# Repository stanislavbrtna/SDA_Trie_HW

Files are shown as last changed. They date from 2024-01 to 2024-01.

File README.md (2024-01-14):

# SDA Trié Hardware Sources
Trié is third iteration of the SDA design, it tries to merge the form factor of Sony Clié V-body and phone functionality of the Palm Treo devices, so Trié. In the pcb directory are KiCad project files for the Boards used in the SDA. In the case Directory there are FreeCAD files for the SDA case. You can find more info about the SDA Project on its [project page](https://hackaday.io/project/35165-sda-the-best-new-pda) on hackaday.io.

This design is work-in-progress.

## Known Bugs

## Case notes

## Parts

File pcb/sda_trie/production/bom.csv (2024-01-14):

Designator | Footprint | Quantity | Value | LCSC Part #
C1 | 0805 | 1 | 100n
C10 | 0805 | 1 | 100n
C11 | 0805 | 1 | 100n
C12 | 0805 | 1 | 100n
C13 | 0805 | 1 | 100n
C14 | 0805 | 1 | 100n
C15 | 0805 | 1 | 100n
C16 | 0805 | 1 | 100n
C17 | 0805 | 1 | 100n
C18 | 0805 | 1 | 100n
C19 | 0805 | 1 | 2.2u
C2 | 0805 | 1 | 100n
C21 | 0805 | 1 | 4.7u
C22 | 0805 | 1 | ??
C23 | 0805 | 1 | ??
C24 | 0805 | 1 | 10u
C25 | 0805 | 1 | 47p
C26 | 0805 | 1 | 47p
C27 | 0805 | 1 | 10u
C28 | 0805 | 1 | 100n
C29 | 0805 | 1 | 2.2u
C3 | 0805 | 1 | ??
C30 | 0805 | 1 | 10u
C31 | 0805 | 1 | 4.7u
C32 | 0805 | 1 | 100n
C33 | 0805 | 1 | 47u
C34 | 0805 | 1 | 100n
C35 | 0805 | 1 | 10u
C36 | 0805 | 1 | 2.2u
C37 | 0805 | 1 | 100n
C38 | 0805 | 1 | 10u
C39 | 0805 | 1 | 4.7u
C4 | 0805 | 1 | ??
C40 | 0805 | 1 | 22u
C41 | 0805 | 1 | 2.2u
C42 | 0805 | 1 | 10u
C43 | 0805 | 1 | 100n
C44 | 0805 | 1 | 100n
C45 | 0805 | 1 | 2.2n
C46 | 0805 | 1 | 100n
C47 | 0805 | 1 | 2.2n
C48 | 0805 | 1 | ??
C49 | 0805 | 1 | 47u
C5 | 0805 | 1 | 100n
C50 | 0805 | 1 | 4.7u
C6 | 0805 | 1 | 2.2u
C7 | 0805 | 1 | 100n
C8 | 0805 | 1 | 2.2u
C9 | 0805 | 1 | 100n
D1 | LED_D3.0mm_FlatTop | 1 | SYS_LED
D2, D4, D7 | D_SOD-123 | 3 | 1N5819HW-7-F
D3 | LED_D3.0mm_FlatTop | 1 | CHRG_LED
D5 | D_SOD-123 | 1 | 1N4148W
D6 | D_SOD-123 | 1 | MBR0520
J1 | PinHeader_1x06_P1.00mm_Vertical | 1 | PROG
J10 | PinHeader_1x02_P1.00mm_Vertical | 1 | SPKR
J11 | 3.5 Jack | 1 | AudioJack
J2 | USB_C_Receptacle_XKB_U262-16XN-4BVC11 | 1 | USB_C_Receptacle_USB2.0
J3 | PinHeader_2x08_P1.00mm_Vertical | 1 | KEYBOARD
J4, J7 | PinHeader_2x05_P1.00mm_Vertical_SMD | 2 | Conn_02x05_Top_Bottom
J5 | PinHeader_1x02_P1.00mm_Horizontal | 1 | BATT
J6 | PinHeader_2x11_P1.00mm_Horizontal | 1 | HINGE
J8 | PinHeader_1x02_P1.00mm_Vertical | 1 | PWR_BTN
J9 | SD-Connector | 1 | Micro_SD_Card_Det
L1 | HCM1A4020V2 | 1 | 4.7uH
L2 | SDN0530MT100 | 1 | 10uH
Q1 | SOT-23 | 1 | IRLML6302
R1 | 0805 | 1 | 10k
R10 | 0805 | 1 | 10k
R11 | 0805 | 1 | 15k
R12 | 0805 | 1 | 10k
R13 | 0805 | 1 | 19K
R14 | 0805 | 1 | 2k
R15 | 0805 | 1 | 47k
R16 | 0805 | 1 | 47k
R17 | 0805 | 1 | 47k
R18 | 0805 | 1 | 47k
R19 | 0805 | 1 | 47k
R2 | 0805 | 1 | 10k
R20 | 0805 | 1 | placeholder
R21 | 0805 | 1 | 47k
R22 | 0805 | 1 | 680K
R23 | 0805 | 1 | 150K
R24 | 0805 | 1 | 470
R25 | 0805 | 1 | 470
R26 | 0805 | 1 | 13k3
R27 | 0805 | 1 | 40k2
R28 | 0805 | 1 | 5.2k
R29 | 0805 | 1 | 5.2k
R3 | 0805 | 1 | 15K
R30 | 0805 | 1 | 0
R4 | 0805 | 1 | 10k
R5 | 0805 | 1 | 15K
R6 | 0805 | 1 | 220
R7 | 0805 | 1 | 27
R8 | 0805 | 1 | 27R
R9 | 0805 | 1 | 470
SW1 | SW_SPST_B3S-1000 | 1 | RESET
TP1 | TestPoint_Pad_D1.0mm | 1 | VREFF
TP2 | TestPoint_Pad_D1.0mm | 1 | TP_VUSB
TP3 | TestPoint_Pad_D1.0mm | 1 | VBATT
TP4 | TestPoint_Pad_D1.0mm | 1 | 3.3V
TP5 | TestPoint_Pad_D1.0mm | 1 | 5V
U10 | LQFP-144_20x20mm_P0.5mm | 1 | STM32H743ZITx
U2 | TSOT-23 | 1 | TLV431
U3 | TSOT-23-6_HandSoldering | 1 | USBLC6
U4 | SOT-23-5_HandSoldering | 1 | AP22802AW5-7
U5 | SSOP-16_3.9x4.9mm_P0.635mm | 1 | FT230XS
U6 | SOT-23-5_HandSoldering | 1 | MCP73831-2-OT
U7 | TSSOP-20_4.4x6.5mm_P0.65mm | 1 | PCM5102
U8 | TSOT-23-5_HandSoldering | 1 | NCP1529
U9 | SOT-23-5_HandSoldering | 1 | LMR62014XMF
Y1 | SMDXT224 | 1 | 16Mhz
Y2 | 32.768K-85SMXR | 1 | 32.768

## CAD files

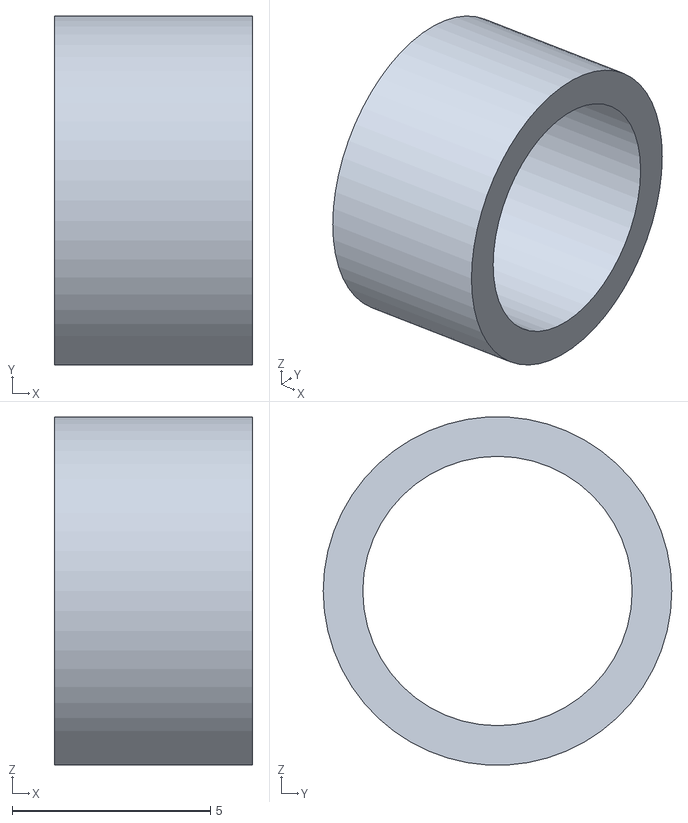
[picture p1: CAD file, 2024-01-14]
case/export/trié-fitting.stl
5.00 x 8.80 x 8.79

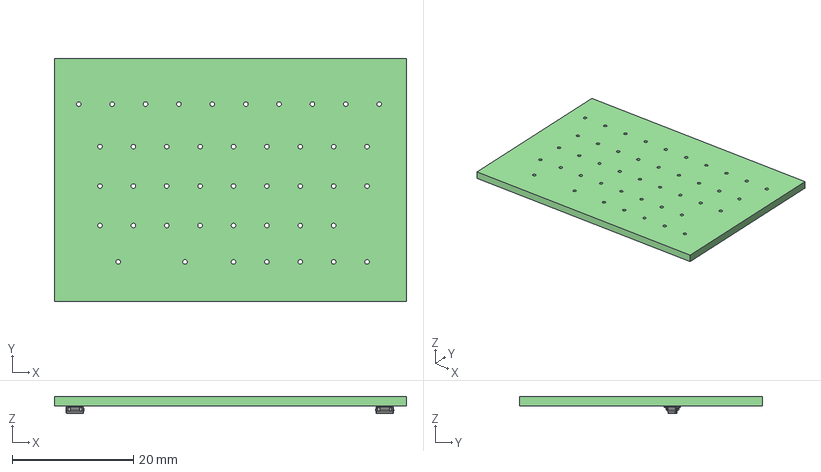
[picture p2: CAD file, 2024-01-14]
pcb/sda_trie/sda_trie_kbd.step
58.0 x 40.0 x 2.85 mm
sda_trie_kbd PCB

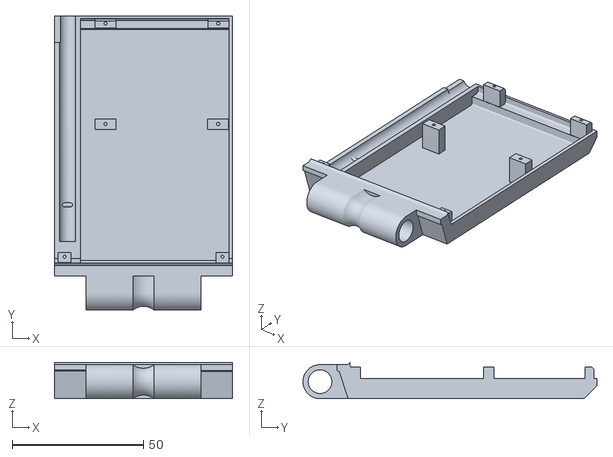
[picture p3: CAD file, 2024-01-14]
case/export/trié-bottom-base.stl
68.0 x 112.0 x 13.9

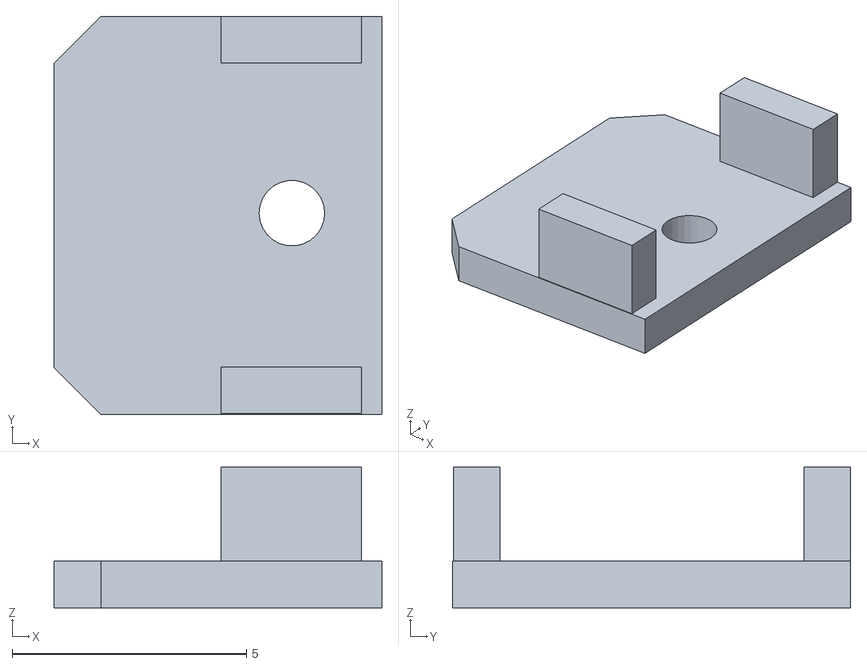
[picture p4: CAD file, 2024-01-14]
case/export/trié-lcd-holder-trie.stl
7.00 x 8.50 x 3.00

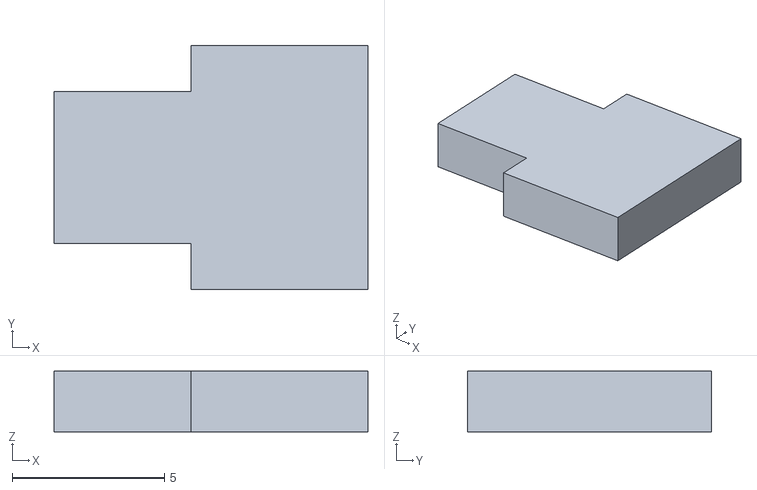
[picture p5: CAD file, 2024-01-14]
case/export/trié-pwr-btn-fillet.stl
10.3 x 8.00 x 2.00

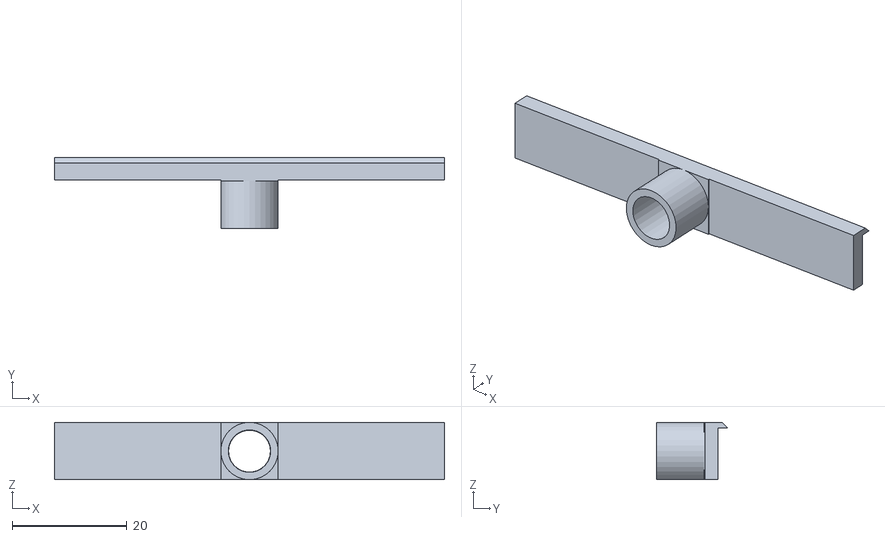
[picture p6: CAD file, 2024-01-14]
case/export/trié-top-hinge.stl
68.0 x 12.5 x 10.0

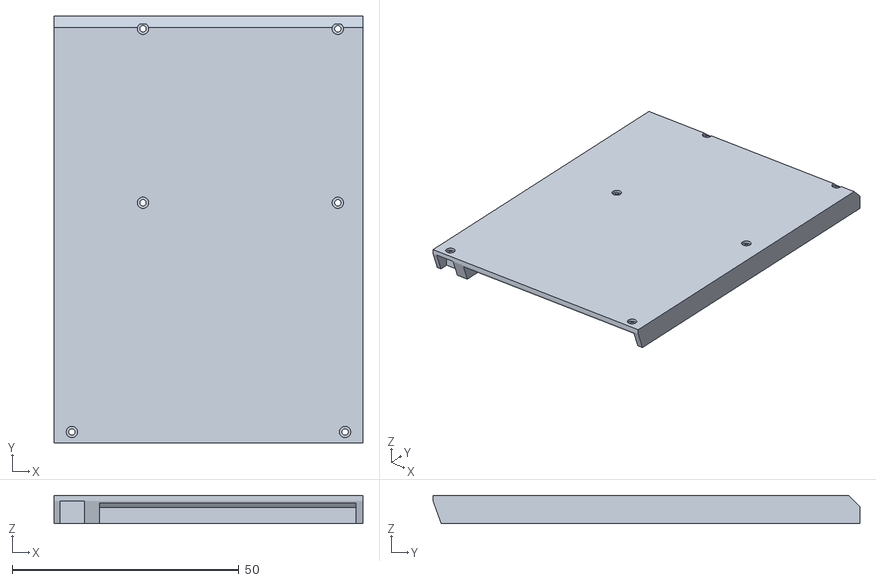
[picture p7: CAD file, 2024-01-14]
case/export/trié-bottom-cover.stl
68.0 x 94.1 x 6.20

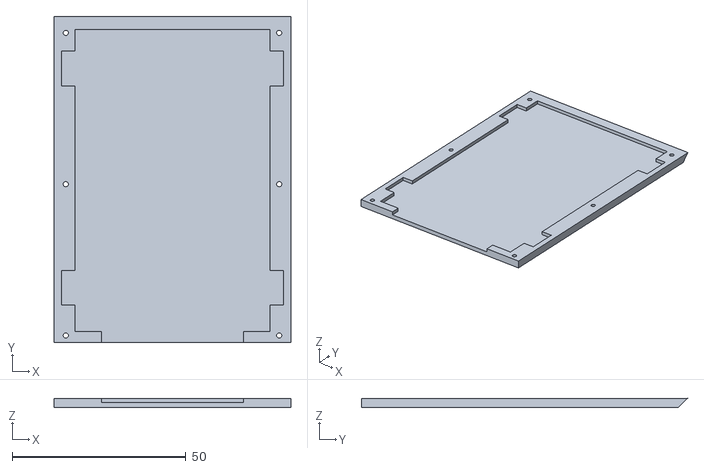
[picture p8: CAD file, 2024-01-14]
case/export/trié-top-cover.stl
68.0 x 93.7 x 2.70

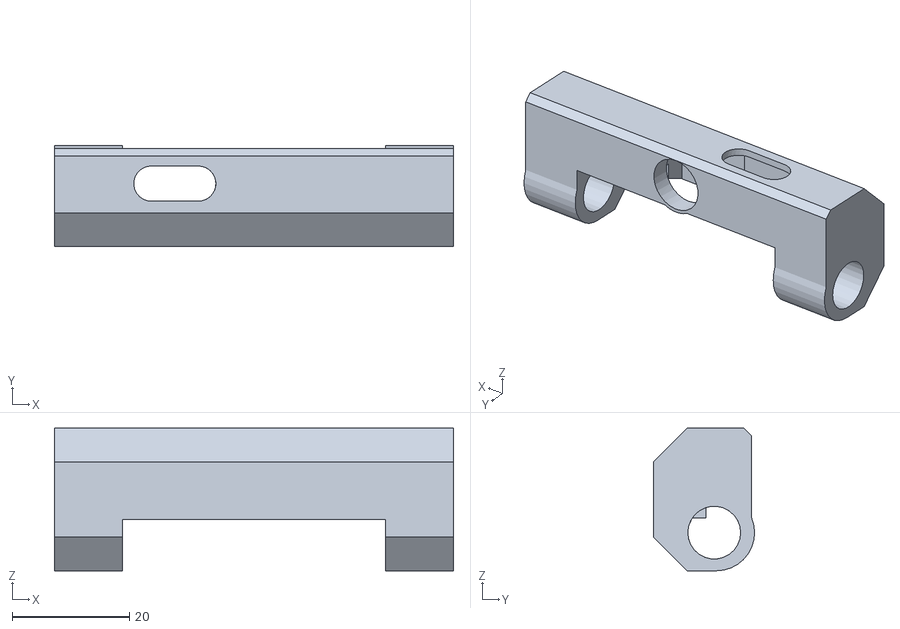
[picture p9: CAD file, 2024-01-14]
case/export/trié-pant.stl
68.0 x 17.2 x 24.3

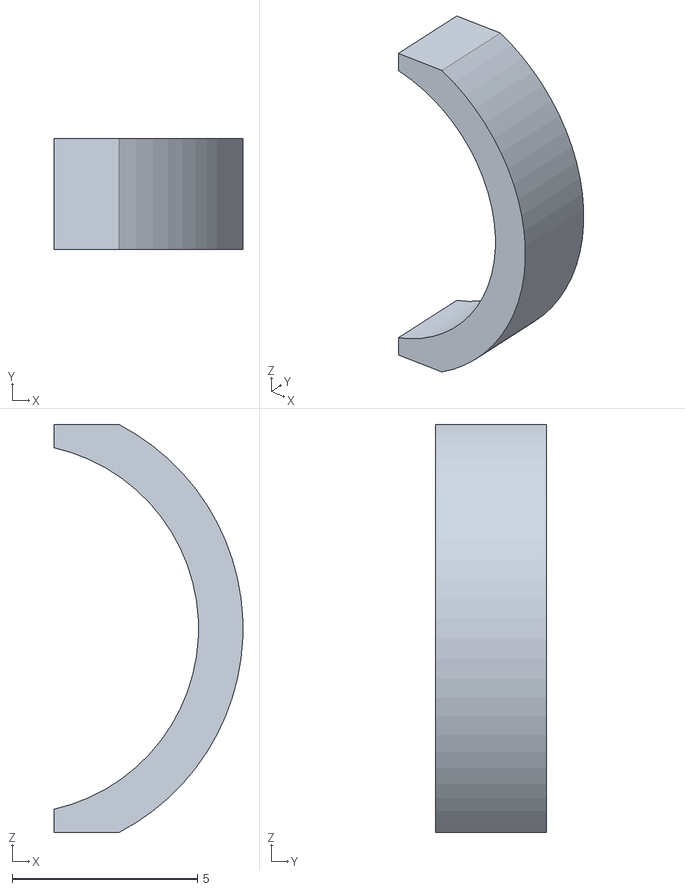
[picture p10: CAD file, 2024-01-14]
case/export/trié-lcd-rot-stop.stl
5.09 x 3.00 x 11.0

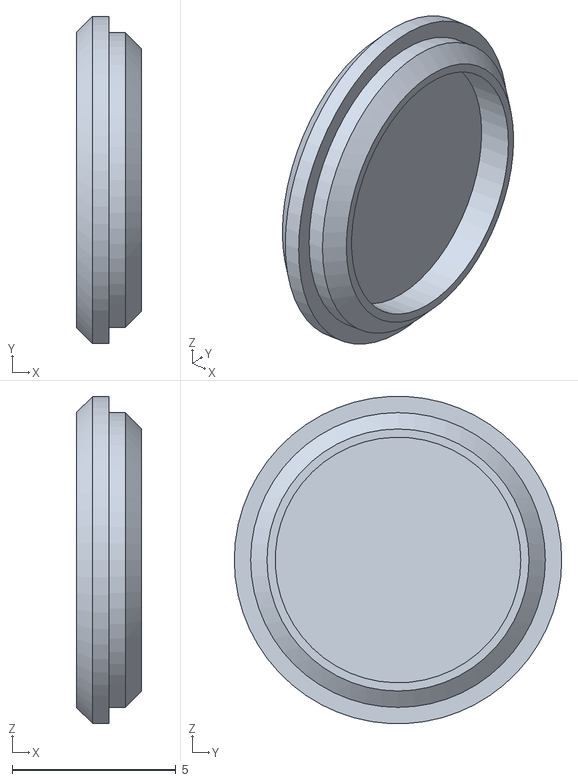
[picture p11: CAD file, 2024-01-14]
case/export/trié-sidecap.stl
2.00 x 10.0 x 9.99

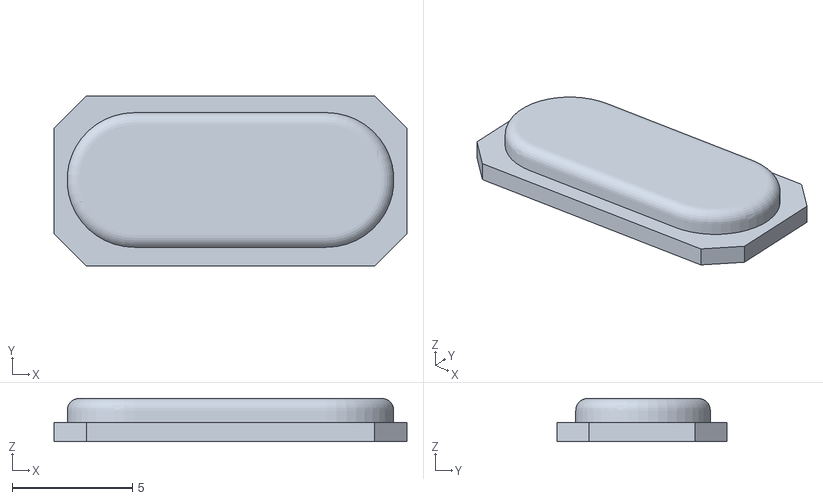
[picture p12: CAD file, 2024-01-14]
case/export/trié-pwrbtn.stl
14.7 x 7.09 x 1.80

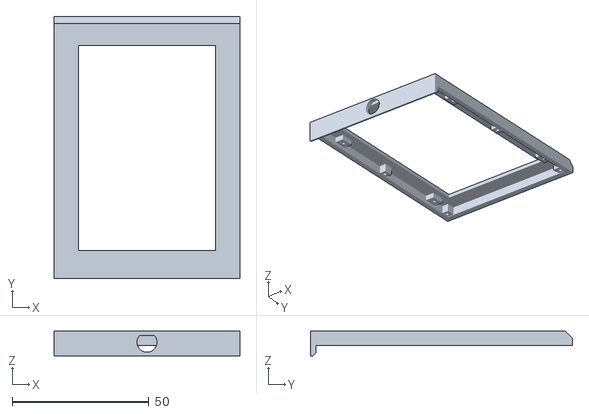
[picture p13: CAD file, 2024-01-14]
case/export/trié-top-base.stl
68.0 x 95.8 x 9.02

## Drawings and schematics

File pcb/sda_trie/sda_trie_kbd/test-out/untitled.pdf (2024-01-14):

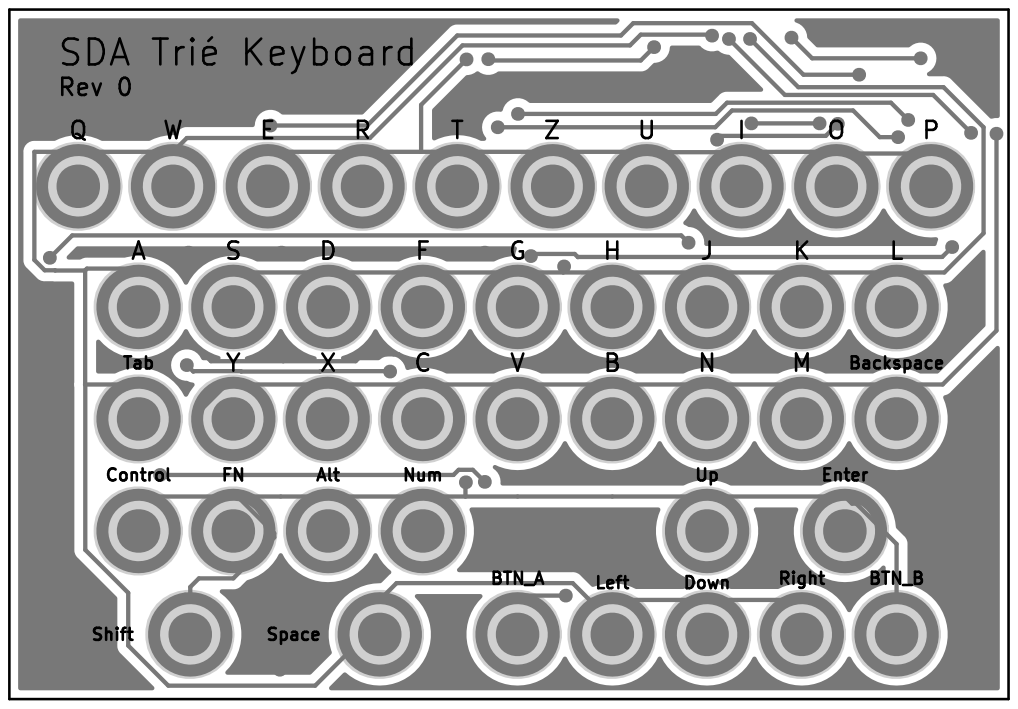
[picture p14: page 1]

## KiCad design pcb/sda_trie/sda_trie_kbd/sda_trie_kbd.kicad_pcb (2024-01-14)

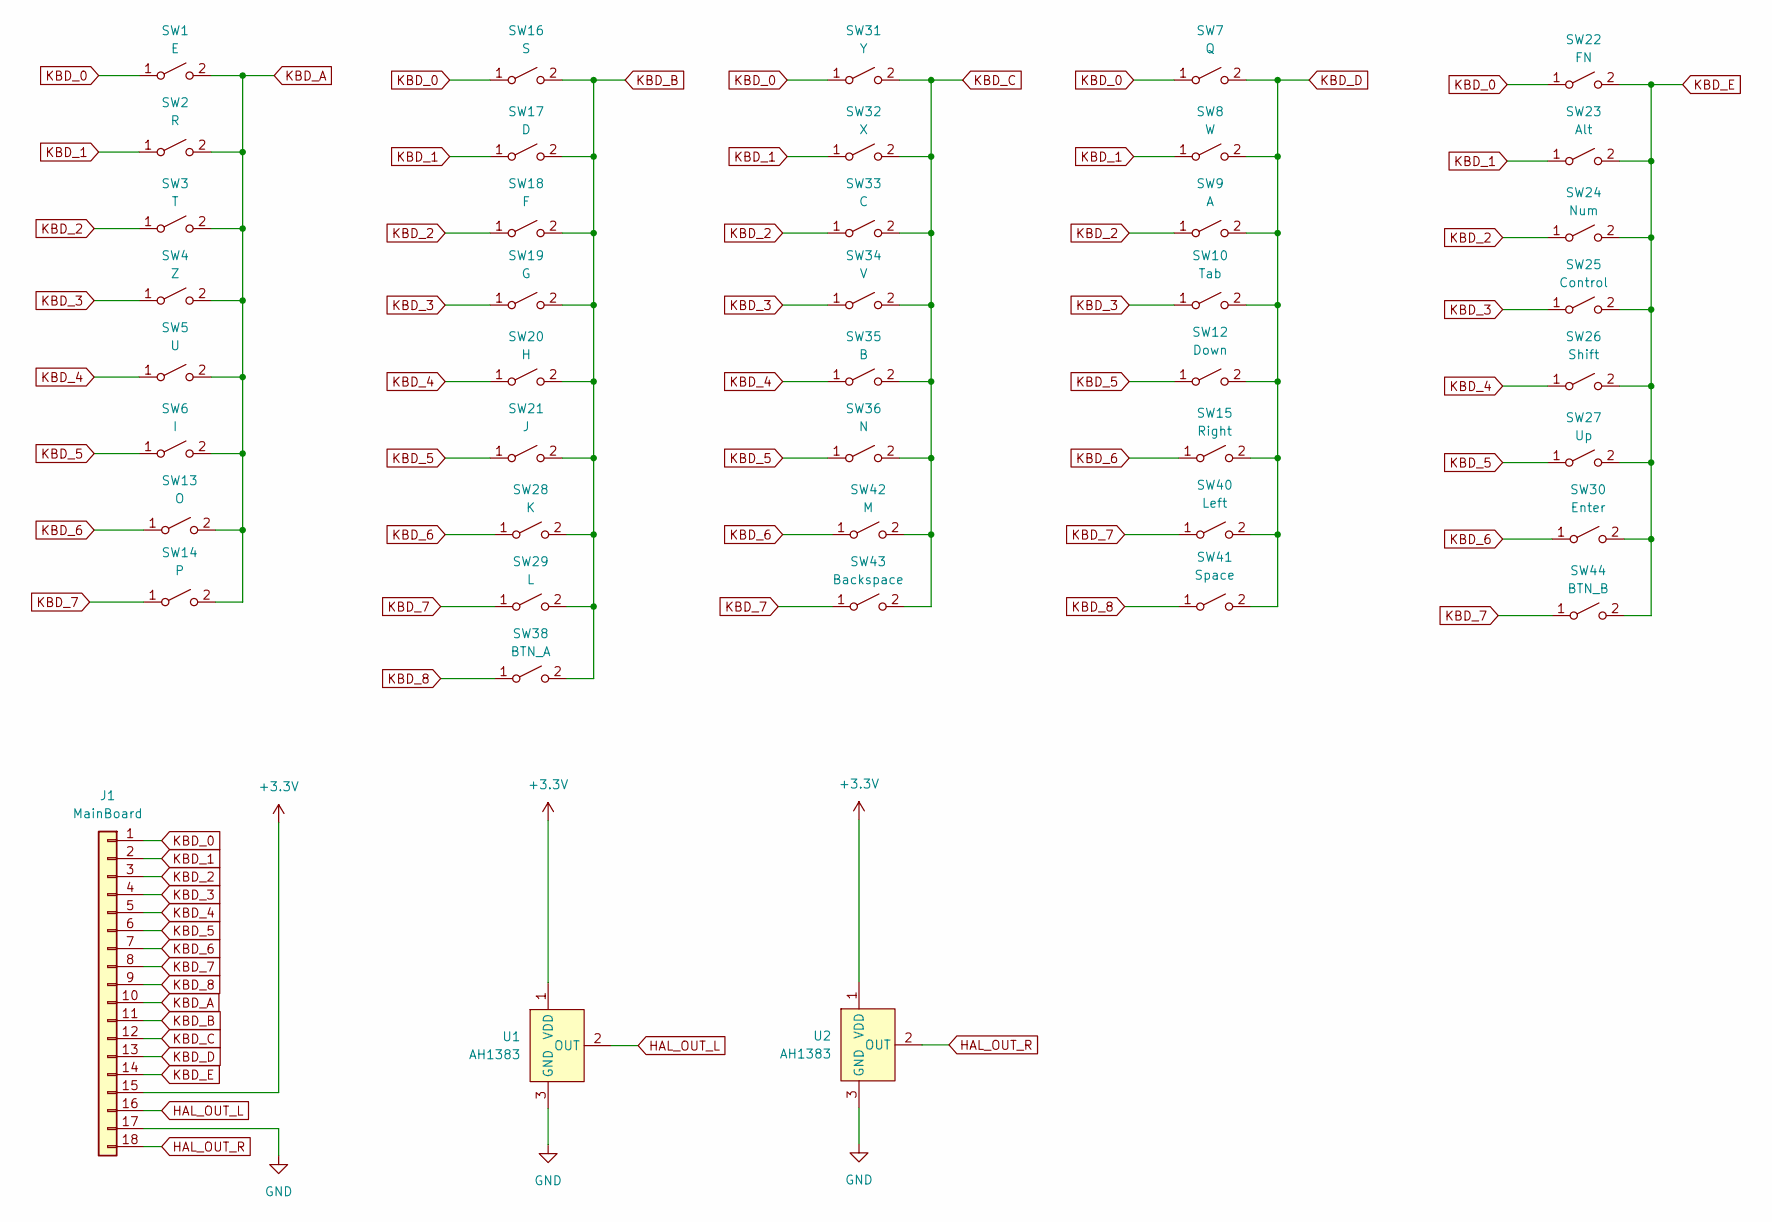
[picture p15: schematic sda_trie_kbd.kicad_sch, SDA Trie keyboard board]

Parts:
J1: MainBoard; TE_1-1734839-8_1x18-1MP_P0.5mm_Horizontal
SW1: E; TACT_4MM
SW2: R; TACT_4MM
SW3: T; TACT_4MM
SW4: Z; TACT_4MM
SW5: U; TACT_4MM
SW6: I; TACT_4MM
SW7: Q; TACT_4MM
SW8: W; TACT_4MM
SW9: A; TACT_4MM
SW10: Tab; TACT_4MM
SW12: Down; TACT_4MM
SW13: O; TACT_4MM
SW14: P; TACT_4MM
SW15: Right; TACT_4MM
SW16: S; TACT_4MM
SW17: D; TACT_4MM
SW18: F; TACT_4MM
SW19: G; TACT_4MM
SW20: H; TACT_4MM
SW21: J; TACT_4MM
SW22: FN; TACT_4MM
SW23: Alt; TACT_4MM
SW24: Num; TACT_4MM
SW25: Control; TACT_4MM
SW26: Shift; TACT_4MM
SW27: Up; TACT_4MM
SW28: K; TACT_4MM
SW29: L; TACT_4MM
SW30: Enter; TACT_4MM
SW31: Y; TACT_4MM
SW32: X; TACT_4MM
SW33: C; TACT_4MM
SW34: V; TACT_4MM
SW35: B; TACT_4MM
SW36: N; TACT_4MM
SW38: BTN_A; TACT_4MM
SW40: Left; TACT_4MM
SW41: Space; TACT_4MM
SW42: M; TACT_4MM
SW43: Backspace; TACT_4MM
SW44: BTN_B; TACT_4MM
U1, U2: AH1383; SOT-23

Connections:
+3.3V: J1.15, U1.1 (VDD), U2.1 (VDD)
GND: J1.17, U1.3 (GND), U2.3 (GND)
HAL_OUT_L: J1.16, U1.2 (OUT)
HAL_OUT_R: J1.18, U2.2 (OUT)
KBD_0: J1.1, SW1.1 (A), SW7.1 (A), SW16.1 (A), SW22.1 (A), SW31.1 (A)
KBD_1: J1.2, SW2.1 (A), SW8.1 (A), SW17.1 (A), SW23.1 (A), SW32.1 (A)
KBD_2: J1.3, SW3.1 (A), SW9.1 (A), SW18.1 (A), SW24.1 (A), SW33.1 (A)
KBD_3: J1.4, SW4.1 (A), SW10.1 (A), SW19.1 (A), SW25.1 (A), SW34.1 (A)
KBD_4: J1.5, SW5.1 (A), SW20.1 (A), SW26.1 (A), SW35.1 (A)
KBD_5: J1.6, SW6.1 (A), SW12.1 (A), SW21.1 (A), SW27.1 (A), SW36.1 (A)
KBD_6: J1.7, SW13.1 (A), SW15.1 (A), SW28.1 (A), SW30.1 (A), SW42.1 (A)
KBD_7: J1.8, SW14.1 (A), SW29.1 (A), SW40.1 (A), SW43.1 (A), SW44.1 (A)
KBD_8: J1.9, SW38.1 (A), SW41.1 (A)
KBD_A: J1.10, SW1.2 (B), SW2.2 (B), SW3.2 (B), SW4.2 (B), SW5.2 (B), SW6.2 (B), SW13.2 (B), SW14.2 (B)
KBD_B: J1.11, SW16.2 (B), SW17.2 (B), SW18.2 (B), SW19.2 (B), SW20.2 (B), SW21.2 (B), SW28.2 (B), SW29.2 (B), SW38.2 (B)
KBD_C: J1.12, SW31.2 (B), SW32.2 (B), SW33.2 (B), SW34.2 (B), SW35.2 (B), SW36.2 (B), SW42.2 (B), SW43.2 (B)
KBD_D: J1.13, SW7.2 (B), SW8.2 (B), SW9.2 (B), SW10.2 (B), SW12.2 (B), SW15.2 (B), SW40.2 (B), SW41.2 (B)
KBD_E: J1.14, SW22.2 (B), SW23.2 (B), SW24.2 (B), SW25.2 (B), SW26.2 (B), SW27.2 (B), SW30.2 (B), SW44.2 (B)

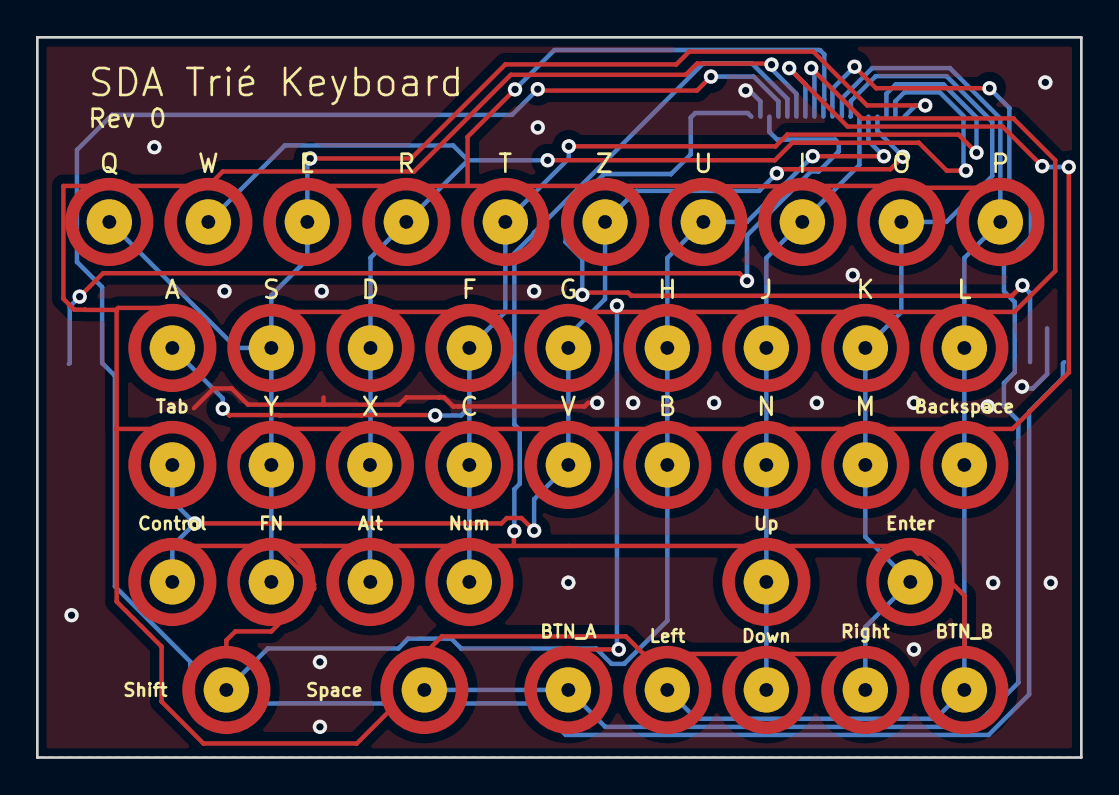
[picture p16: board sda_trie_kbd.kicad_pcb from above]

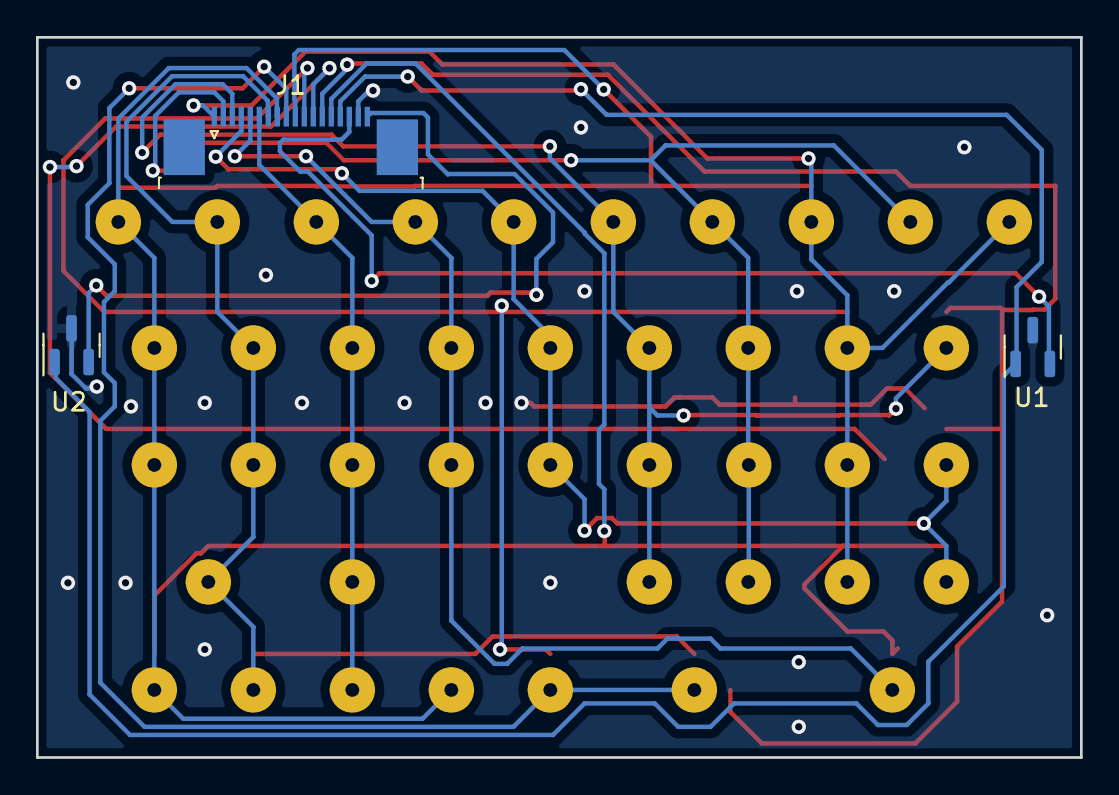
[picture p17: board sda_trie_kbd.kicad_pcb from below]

Board: 2 copper layers, 58.0 x 40.0 mm, 44 parts (3 on the bottom side), 18 nets.

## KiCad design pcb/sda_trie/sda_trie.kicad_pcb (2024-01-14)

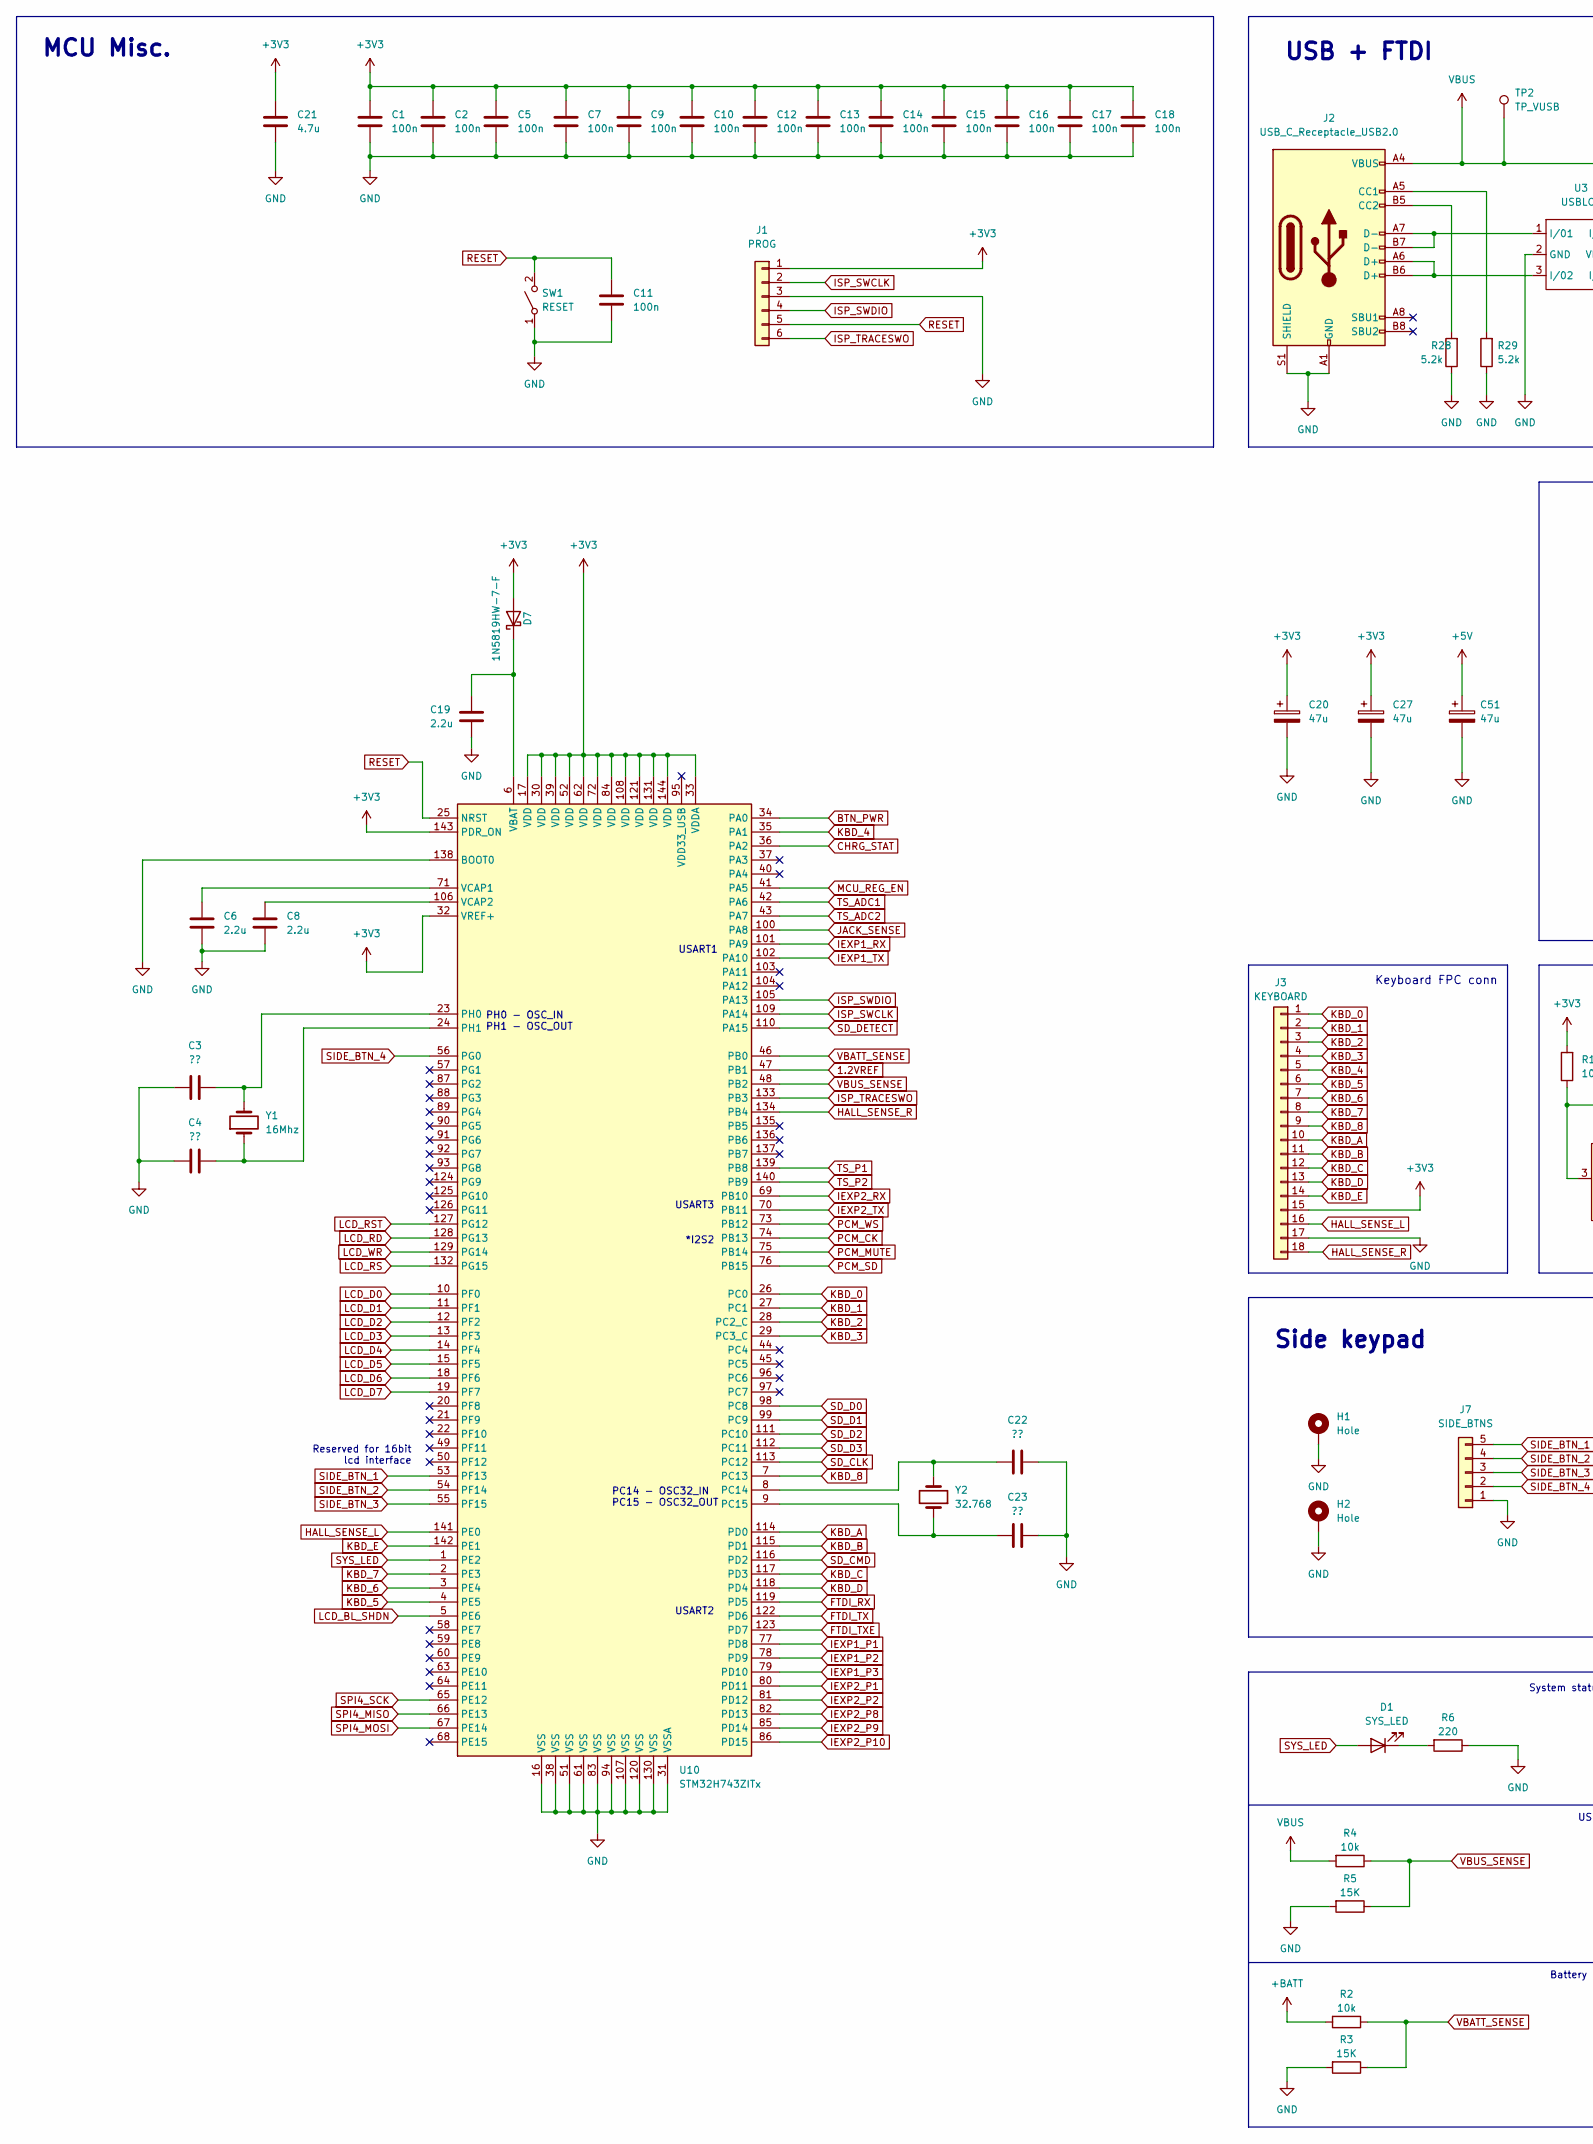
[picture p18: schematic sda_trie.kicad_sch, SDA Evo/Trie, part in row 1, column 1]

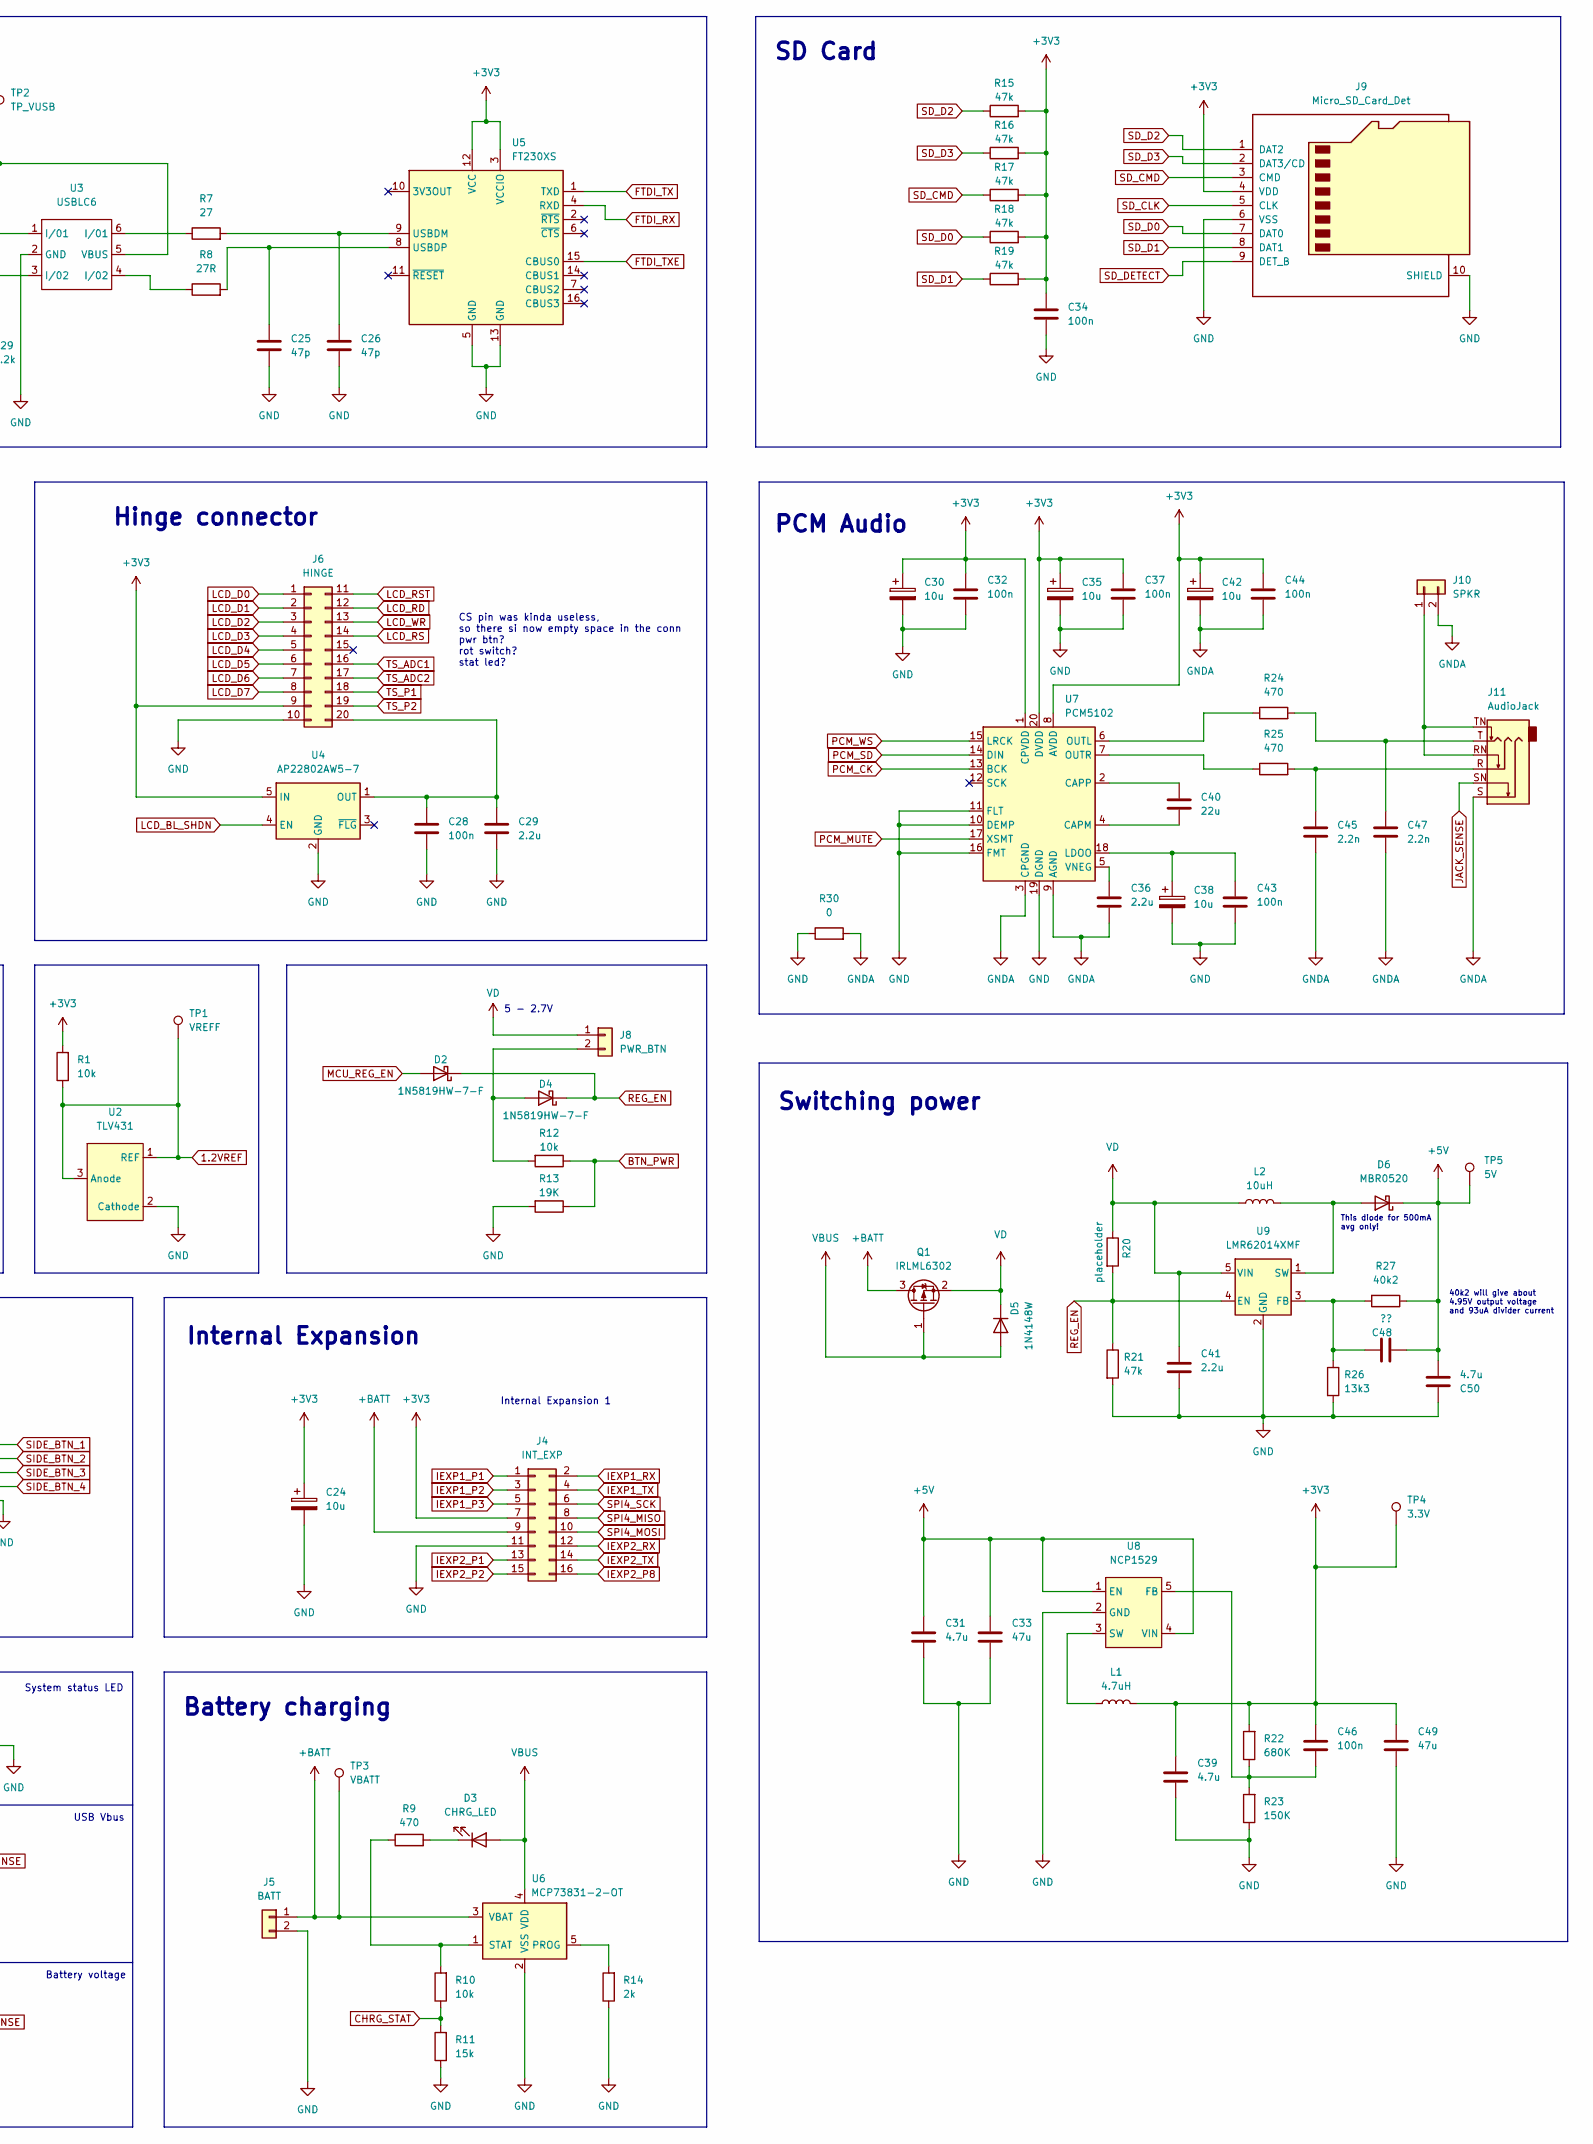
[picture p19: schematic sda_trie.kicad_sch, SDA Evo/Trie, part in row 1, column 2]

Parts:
C1, C2, C5, C7, C9, C10, C11, C12, C13, C14, C15, C16, C17, C18, C28, C32, C34, C37, C43, C44, C46: 100n; C_0805_2012Metric_Pad1.18x1.45mm_HandSolder
C3, C4, C22, C23, C48: ??; C_0805_2012Metric_Pad1.18x1.45mm_HandSolder
C6, C8, C19, C29, C36, C41: 2.2u; C_0805_2012Metric_Pad1.18x1.45mm_HandSolder
C20, C27, C51: 47u; CP_EIA-7343-15_Kemet-W_Pad2.25x2.55mm_HandSolder
C21, C31, C39, C50: 4.7u; C_0805_2012Metric_Pad1.18x1.45mm_HandSolder
C24, C30, C35, C38, C42: 10u; C_0805_2012Metric_Pad1.18x1.45mm_HandSolder
C25, C26: 47p; C_0805_2012Metric_Pad1.18x1.45mm_HandSolder
C33, C49: 47u; C_0805_2012Metric_Pad1.18x1.45mm_HandSolder
C40: 22u; C_0805_2012Metric_Pad1.18x1.45mm_HandSolder
C45, C47: 2.2n; C_0805_2012Metric_Pad1.18x1.45mm_HandSolder
D1: SYS_LED; LED_D3.0mm_FlatTop
D2, D4, D7: 1N5819HW-7-F; D_SOD-123
D3: CHRG_LED; LED_D3.0mm_FlatTop
D5: 1N4148W; D_SOD-123
D6: MBR0520; D_SOD-123
H1, H2: Hole; Mounting_Wuerth_WA-SMSI-M1.6_H1.5mm_9774015633
J1: PROG; PinHeader_1x06_P1.00mm_Vertical
J2: USB_C_Receptacle_USB2.0; USB_C_Receptacle_XKB_U262-16XN-4BVC11
J3: KEYBOARD; TE_1-1734839-8_1x18-1MP_P0.5mm_Horizontal
J4: INT_EXP; PinHeader_2x08_P1.00mm_Vertical_SMD
J5: BATT; PinHeader_1x02_P2.54mm_Horizontal
J6: HINGE; PinHeader_2x10_P1.00mm_Horizontal
J7: SIDE_BTNS; PinHeader_1x05_P1.00mm_Horizontal
J8: PWR_BTN; PinHeader_1x02_P1.00mm_Vertical
J9: Micro_SD_Card_Det; SD-Connector
J10: SPKR; PinHeader_1x02_P1.00mm_Vertical
J11: AudioJack; 3.5 Jack
L1: 4.7uH; HCM1A4020V2
L2: 10uH; SDN0530MT100
Q1: IRLML6302; SOT-23
R1, R2, R4, R10, R12: 10k; R_0805_2012Metric_Pad1.20x1.40mm_HandSolder
R3, R5: 15K; R_0805_2012Metric_Pad1.20x1.40mm_HandSolder
R6: 220; R_0805_2012Metric_Pad1.20x1.40mm_HandSolder
R7: 27; R_0805_2012Metric_Pad1.20x1.40mm_HandSolder
R8: 27R; R_0805_2012Metric_Pad1.20x1.40mm_HandSolder
R9, R24, R25: 470; R_0805_2012Metric_Pad1.20x1.40mm_HandSolder
R11: 15k; R_0805_2012Metric_Pad1.20x1.40mm_HandSolder
R13: 19K; R_0805_2012Metric_Pad1.20x1.40mm_HandSolder
R14: 2k; R_0805_2012Metric_Pad1.20x1.40mm_HandSolder
R15, R16, R17, R18, R19, R21: 47k; R_0805_2012Metric_Pad1.20x1.40mm_HandSolder
R20: placeholder; R_0805_2012Metric_Pad1.20x1.40mm_HandSolder
R22: 680K; R_0805_2012Metric_Pad1.20x1.40mm_HandSolder
R23: 150K; R_0805_2012Metric_Pad1.20x1.40mm_HandSolder
R26: 13k3; R_0805_2012Metric_Pad1.20x1.40mm_HandSolder
R27: 40k2; R_0805_2012Metric_Pad1.20x1.40mm_HandSolder
R28, R29: 5.2k; R_0805_2012Metric_Pad1.20x1.40mm_HandSolder
R30: 0; R_0805_2012Metric_Pad1.20x1.40mm_HandSolder
SW1: RESET; SW_SPST_B3S-1000
TP1: VREFF; TestPoint_Pad_D1.0mm
TP2: TP_VUSB; TestPoint_Pad_D1.0mm
TP3: VBATT; TestPoint_Pad_D1.0mm
TP4: 3.3V; TestPoint_Pad_D1.0mm
TP5: 5V; TestPoint_Pad_D1.0mm
U2: TLV431; TSOT-23
U3: USBLC6; TSOT-23-6_HandSoldering
U4: AP22802AW5-7; SOT-23-5_HandSoldering
U5: FT230XS; SSOP-16_3.9x4.9mm_P0.635mm
U6: MCP73831-2-OT; SOT-23-5_HandSoldering
U7: PCM5102; TSSOP-20_4.4x6.5mm_P0.65mm
U8: NCP1529; TSOT-23-5_HandSoldering
U9: LMR62014XMF; SOT-23-5_HandSoldering
U10: STM32H743ZITx; LQFP-144_20x20mm_P0.5mm
Y1: 16Mhz; SMDXT224
Y2: 32.768; 32.768K-85SMXR

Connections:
1.2VREF: R1.1, TP1.1, U2.1 (REF), U2.3 (Anode), U10.47 (PB1)
+3V3: C1.1, C2.1, C5.1, C7.1, C9.1, C10.1, C12.1, C13.1, C14.1, C15.1, C16.1, C17.1, C18.1, C20.1, C21.1, C24.1, C27.1, C30.1, C32.1, C34.1, C35.1, C37.1, C39.1, C42.1, C44.1, C46.1, C49.1, D7.2 (A), J1.1, J3.15, J4.7, J6.9, J9.4 (VDD), L1.2, R1.2, R15.2, R16.2, R17.2, R18.2, R19.2, R22.2, TP4.1, U4.5 (IN), U5.3 (VCCIO), U5.12 (VCC), U7.1 (CPVDD), U7.8 (AVDD), U7.20 (DVDD), U10.17 (VDD), U10.30 (VDD), U10.32 (VREF+), U10.33 (VDDA), U10.39 (VDD), U10.52 (VDD), U10.62 (VDD), U10.72 (VDD), U10.84 (VDD), U10.108 (VDD), U10.121 (VDD), U10.131 (VDD), U10.143 (PDR_ON), U10.144 (VDD)
+5V: C31.1, C33.1, C48.2, C50.1, C51.1, D6.1 (K), R27.1, TP5.1, U8.1 (EN), U8.4 (VIN)
+BATT: J4.9, J5.1, Q1.3 (D), R2.2, TP3.1, U6.3 (VBAT)
BTN_PWR: R12.1, R13.1, U10.34 (PA0)
CHRG_STAT: R10.1, R11.2, U10.36 (PA2)
FTDI_RX: U5.4 (RXD), U10.119 (PD5)
FTDI_TX: U5.1 (TXD), U10.122 (PD6)
FTDI_TXE: U5.15 (CBUS0), U10.123 (PD7)
GND: C1.2, C2.2, C3.1, C4.1, C5.2, C6.2, C7.2, C8.2, C9.2, C10.2, C11.2, C12.2, C13.2, C14.2, C15.2, C16.2, C17.2, C18.2, C19.2, C20.2, C21.2, C22.1, C23.1, C24.2, C25.2, C26.2, C27.2, C28.2, C29.2, C30.2, C31.2, C32.2, C33.2, C34.2, C35.2, C37.2, C38.2, C39.2, C41.2, C43.2, C49.2, C50.2, C51.2, H1.1, H2.1, J1.3, J2.A1 (GND), J2.A12 (GND), J2.B1 (GND), J2.B12 (GND), J2.S1 (SHIELD), J3.17, J4.11, J5.2, J6.10, J7.1, J9.6 (VSS), J9.10 (SHIELD), R3.2, R5.2, R6.1, R11.1, R13.2, R14.1, R21.2, R23.1, R26.2, R28.1, R29.1, R30.1, SW1.1 (A), U2.2 (Cathode), U3.2 (GND), U4.2 (GND), U5.5 (GND), U5.13 (GND), U6.2 (VSS), U7.10 (DEMP), U7.11 (FLT), U7.16 (FMT), U7.19 (DGND), U8.2 (GND), U9.2 (GND), U10.16 (VSS), U10.31 (VSSA), U10.38 (VSS), U10.51 (VSS), U10.61 (VSS), U10.83 (VSS), U10.94 (VSS), U10.107 (VSS), U10.120 (VSS), U10.130 (VSS), U10.138 (BOOT0)
GNDA: C36.2, C42.2, C44.2, C45.2, C47.2, J10.2, J11.S, R30.2, U7.3 (CPGND), U7.9 (AGND)
HALL_SENSE_L: J3.16, U10.141 (PE0)
HALL_SENSE_R: J3.18, U10.134 (PB4)
IEXP1_P1: J4.1, U10.77 (PD8)
IEXP1_P2: J4.3, U10.78 (PD9)
IEXP1_P3: J4.5, U10.79 (PD10)
IEXP1_RX: J4.2, U10.101 (PA9)
IEXP1_TX: J4.4, U10.102 (PA10)
IEXP2_P1: J4.13, U10.80 (PD11)
IEXP2_P2: J4.15, U10.81 (PD12)
IEXP2_P8: J4.16, U10.82 (PD13)
IEXP2_P9: U10.85 (PD14)
IEXP2_P10: U10.86 (PD15)
IEXP2_RX: J4.12, U10.69 (PB10)
IEXP2_TX: J4.14, U10.70 (PB11)
ISP_SWCLK: J1.2, U10.109 (PA14)
ISP_SWDIO: J1.4, U10.105 (PA13)
ISP_TRACESWO: J1.6, U10.133 (PB3)
JACK_SENSE: J11.SN, U10.100 (PA8)
KBD_0: J3.1, U10.26 (PC0)
KBD_1: J3.2, U10.27 (PC1)
KBD_2: J3.3, U10.28 (PC2_C)
KBD_3: J3.4, U10.29 (PC3_C)
KBD_4: J3.5, U10.35 (PA1)
KBD_5: J3.6, U10.4 (PE5)
KBD_6: J3.7, U10.3 (PE4)
KBD_7: J3.8, U10.2 (PE3)
KBD_8: J3.9, U10.7 (PC13)
KBD_A: J3.10, U10.114 (PD0)
KBD_B: J3.11, U10.115 (PD1)
KBD_C: J3.12, U10.117 (PD3)
KBD_D: J3.13, U10.118 (PD4)
KBD_E: J3.14, U10.142 (PE1)
LCD_BL_SHDN: U4.4 (EN), U10.5 (PE6)
LCD_D0: J6.1, U10.10 (PF0)
LCD_D1: J6.2, U10.11 (PF1)
LCD_D2: J6.3, U10.12 (PF2)
LCD_D3: J6.4, U10.13 (PF3)
LCD_D4: J6.5, U10.14 (PF4)
LCD_D5: J6.6, U10.15 (PF5)
LCD_D6: J6.7, U10.18 (PF6)
LCD_D7: J6.8, U10.19 (PF7)
LCD_RD: J6.12, U10.128 (PG13)
LCD_RS: J6.14, U10.132 (PG15)
LCD_RST: J6.11, U10.127 (PG12)
LCD_WR: J6.13, U10.129 (PG14)
MCU_REG_EN: D2.2 (A), U10.41 (PA5)
unnamed: C3.2, U10.23 (PH0), Y1.2
unnamed: C4.2, U10.24 (PH1), Y1.1
unnamed: C6.1, U10.71 (VCAP1)
unnamed: C8.1, U10.106 (VCAP2)
unnamed: C19.1, D7.1 (K), U10.6 (VBAT)
unnamed: C22.2, U10.8 (PC14), Y2.2
unnamed: C23.2, U10.9 (PC15), Y2.1
unnamed: C25.1, R8.2, U5.8 (USBDP)
unnamed: C26.1, R7.2, U5.9 (USBDM)
unnamed: C28.1, C29.1, J6.20, U4.1 (OUT)
unnamed: C36.1, U7.5 (VNEG)
unnamed: C38.1, C43.1, U7.18 (LDOO)
unnamed: C40.1, U7.2 (CAPP)
unnamed: C40.2, U7.4 (CAPM)
unnamed: C45.1, J11.R, R25.2
unnamed: C46.2, R22.1, R23.2, U8.5 (FB)
unnamed: C47.1, J11.T, R24.2
unnamed: C48.1, R26.1, R27.2, U9.3 (FB)
unnamed: D1.1 (K), R6.2
unnamed: D3.1 (K), R9.2
unnamed: D4.2 (A), J8.2, R12.2
unnamed: D6.2 (A), L2.2, U9.1 (SW)
unnamed: J2.A5 (CC1), R29.2
unnamed: J2.A6 (D+), J2.B6 (D+), U3.3 (I/02)
unnamed: J2.A7 (D-), J2.B7 (D-), U3.1 (I/01)
unnamed: J2.B5 (CC2), R28.2
unnamed: J10.1, J11.RN, J11.TN
unnamed: L1.1, U8.3 (SW)
unnamed: R7.1, U3.6 (I/01)
unnamed: R8.1, U3.4 (I/02)
unnamed: R9.1, R10.2, U6.1 (STAT)
unnamed: R14.2, U6.5 (PROG)
unnamed: R24.1, U7.6 (OUTL)
unnamed: R25.1, U7.7 (OUTR)
PCM_CK: U7.13 (BCK), U10.74 (PB13)
PCM_MUTE: U7.17 (XSMT), U10.75 (PB14)
PCM_SD: U7.14 (DIN), U10.76 (PB15)
PCM_WS: U7.15 (LRCK), U10.73 (PB12)
REG_EN: D2.1 (K), D4.1 (K), R20.2, R21.1, U9.4 (EN)
RESET: C11.1, J1.5, SW1.2 (B), U10.25 (NRST)
SD_CLK: J9.5 (CLK), U10.113 (PC12)
SD_CMD: J9.3 (CMD), R17.1, U10.116 (PD2)
SD_D0: J9.7 (DAT0), R18.1, U10.98 (PC8)
SD_D1: J9.8 (DAT1), R19.1, U10.99 (PC9)
SD_D2: J9.1 (DAT2), R15.1, U10.111 (PC10)
SD_D3: J9.2 (DAT3/CD), R16.1, U10.112 (PC11)
SD_DETECT: J9.9 (DET_B), U10.110 (PA15)
SIDE_BTN_1: J7.5, U10.53 (PF13)
SIDE_BTN_2: J7.4, U10.54 (PF14)
SIDE_BTN_3: J7.3, U10.55 (PF15)
SIDE_BTN_4: J7.2, U10.56 (PG0)
SPI4_MISO: J4.8, U10.66 (PE13)
SPI4_MOSI: J4.10, U10.67 (PE14)
SPI4_SCK: J4.6, U10.65 (PE12)
SYS_LED: D1.2 (A), U10.1 (PE2)
TS_ADC1: J6.16, U10.42 (PA6)
TS_ADC2: J6.17, U10.43 (PA7)
TS_P1: J6.18, U10.139 (PB8)
TS_P2: J6.19, U10.140 (PB9)
VBATT_SENSE: R2.1, R3.1, U10.46 (PB0)
VBUS: D3.2 (A), D5.2 (A), J2.A4 (VBUS), J2.A9 (VBUS), J2.B4 (VBUS), J2.B9 (VBUS), Q1.1 (G), R4.2, TP2.1, U3.5 (VBUS), U6.4 (VDD)
VBUS_SENSE: R4.1, R5.1, U10.48 (PB2)
VD: C41.1, D5.1 (K), J8.1, L2.1, Q1.2 (S), R20.1, U9.5 (VIN)

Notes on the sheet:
MCU Misc.
Battery voltage
USART1
*I2S2
Internal Expansion 1
40k2 will give about 4.95V output voltage and 93uA divider current
Internal Expansion
USART2
USB + FTDI
SD Card
System status LED
USART3
PCM Audio
Keyboard FPC conn
5 - 2.7V
PH0 - OSC_IN PH1 - OSC_OUT
Reserved for 16bit lcd interface
CS pin was kinda useless, so there si now empty space in the conn pwr btn? rot switch? stat led?
Switching power
Hinge connector
This diode for 500mA avg only!
Side keypad
USB Vbus
PC14 - OSC32_IN PC15 - OSC32_OUT
Battery charging

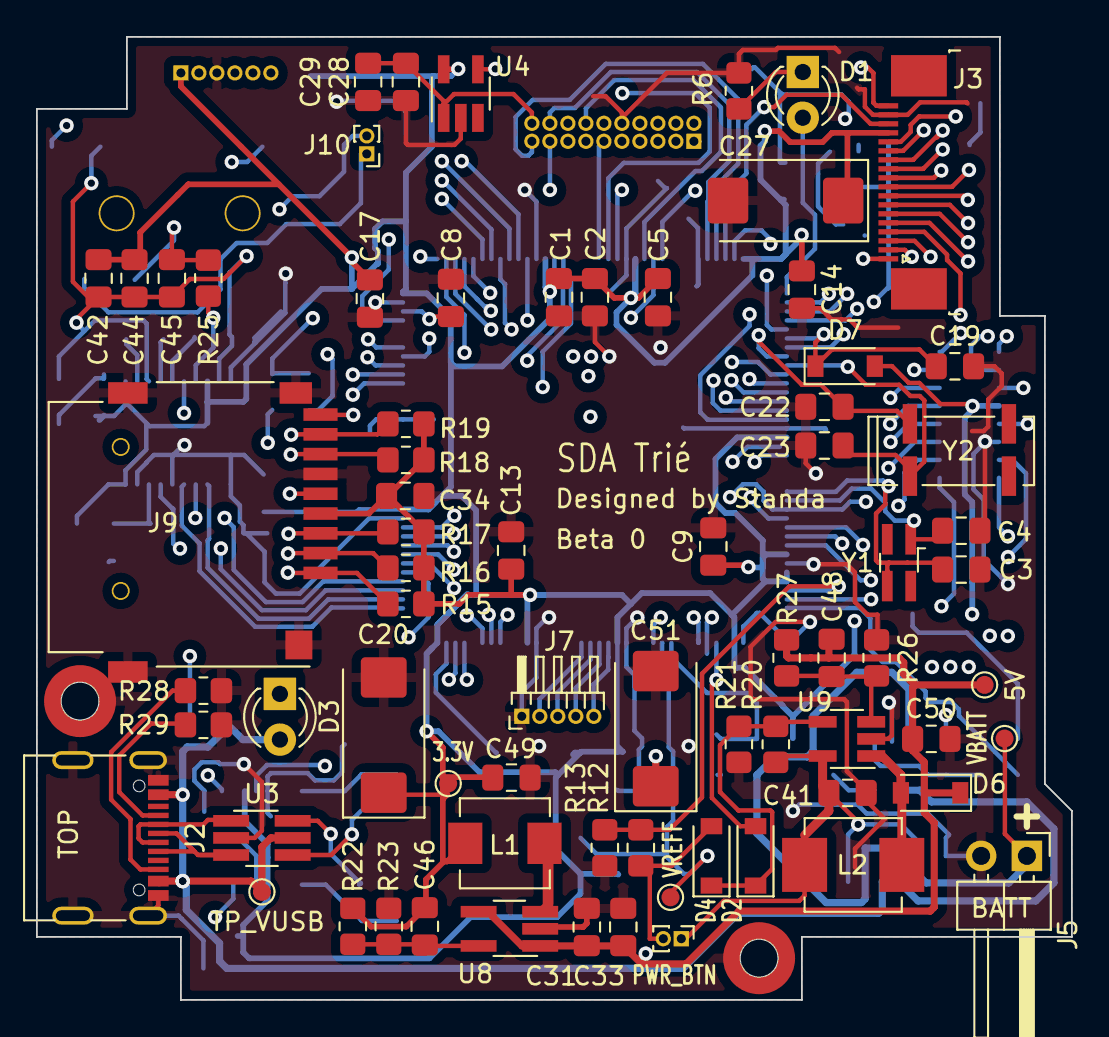
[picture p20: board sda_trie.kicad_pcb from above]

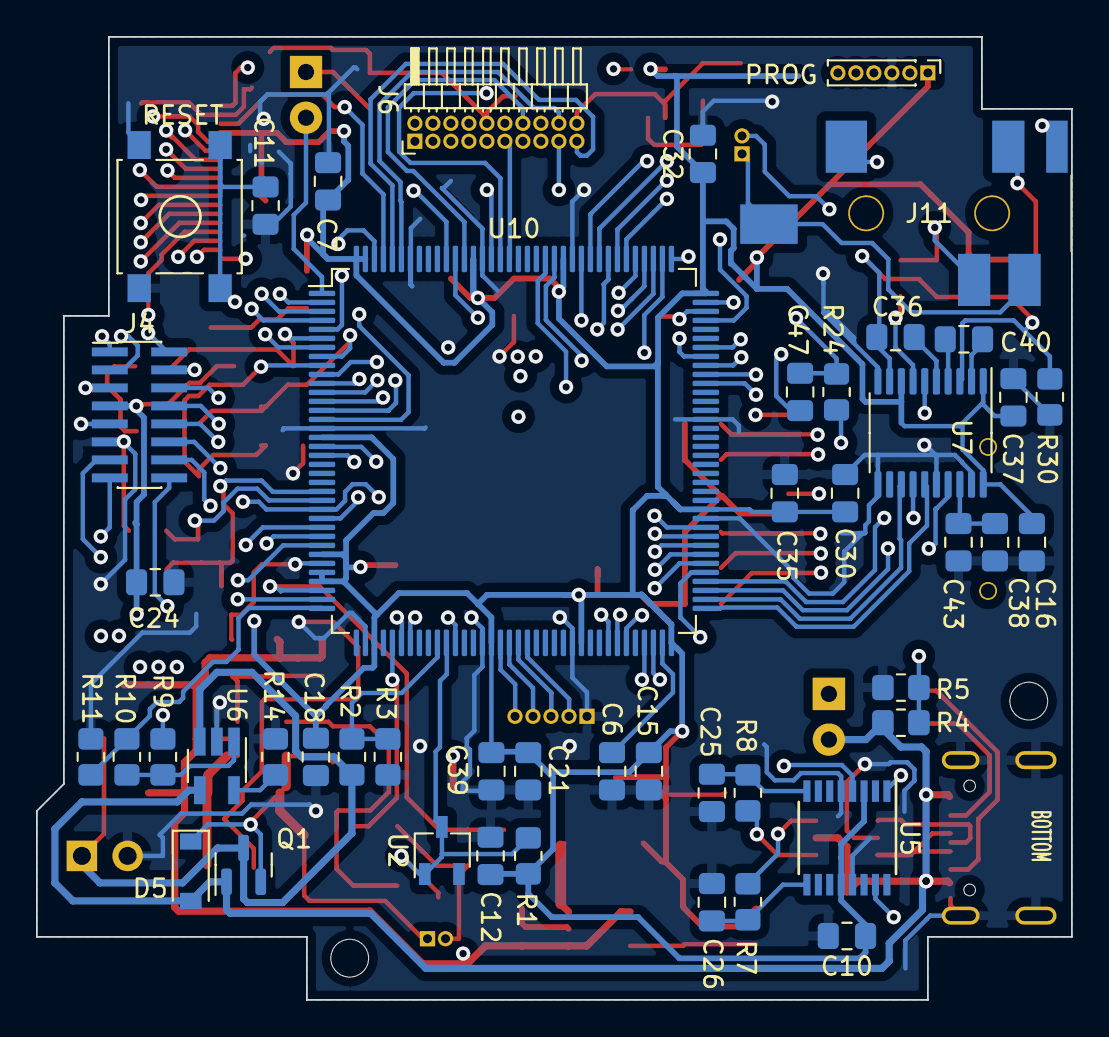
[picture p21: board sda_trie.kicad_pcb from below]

Board: 4 copper layers, 57.5 x 53.5 mm, 121 parts (47 on the bottom side), 118 nets.
